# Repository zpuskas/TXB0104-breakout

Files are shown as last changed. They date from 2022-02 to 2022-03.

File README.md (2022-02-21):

# TXB0104 Breadboard Breakout

Breakout board for the TXB0104 bidirectional voltage-level translator IC with
automatic direction sensing. The main difference of this board compared to
[SparkFun's Voltage-Level Translator Breakout](https://www.sparkfun.com/products/11771)
is that the OE pin is independent, and not soldered to VCCA by default,
allowing for any side of the communication to be in control of the data flow
out of the box.

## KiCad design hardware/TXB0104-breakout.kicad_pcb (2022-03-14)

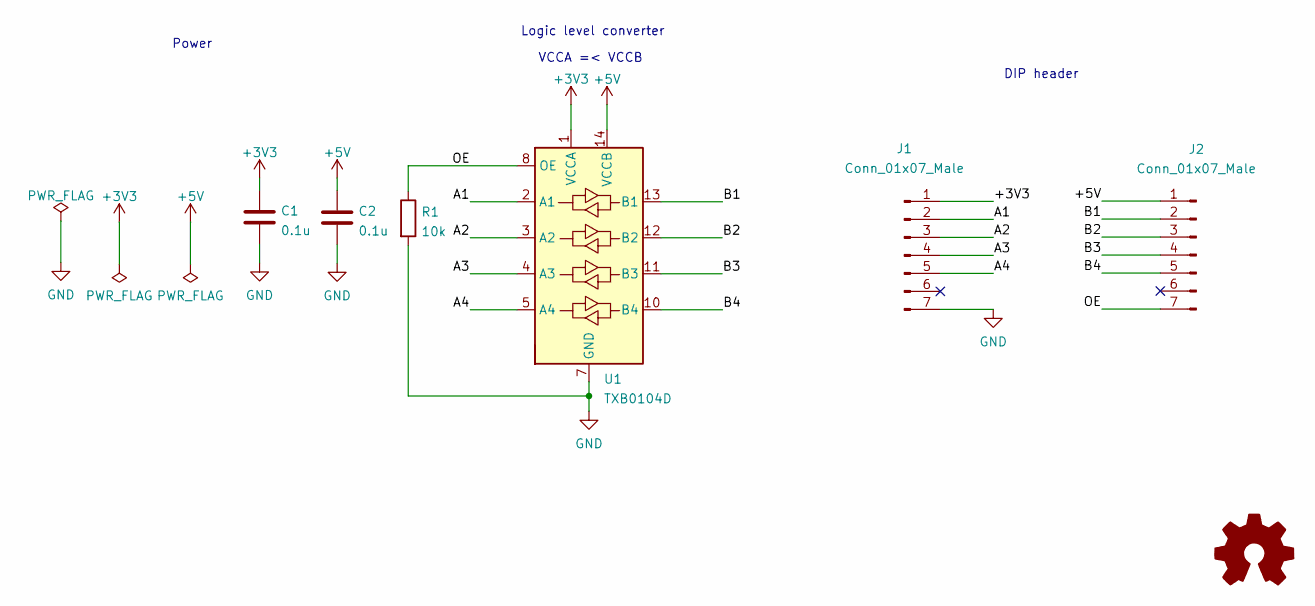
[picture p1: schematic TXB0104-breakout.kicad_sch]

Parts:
C1, C2: 0.1u; C_0805_2012Metric_Pad1.18x1.45mm_HandSolder
J1, J2: Conn_01x07_Male; PinHeader_1x07_P2.54mm_Vertical
R1: 10k; R_0805_2012Metric_Pad1.20x1.40mm_HandSolder
U1: TXB0104D; SOIC-14_3.9x8.7mm_P1.27mm

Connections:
+3V3: C1.1, J1.1, U1.1 (VCCA)
+5V: C2.1, J2.1, U1.14 (VCCB)
/A1: J1.2, U1.2 (A1)
/A2: J1.3, U1.3 (A2)
/A3: J1.4, U1.4 (A3)
/A4: J1.5, U1.5 (A4)
/B1: J2.2, U1.13 (B1)
/B2: J2.3, U1.12 (B2)
/B3: J2.4, U1.11 (B3)
/B4: J2.5, U1.10 (B4)
/OE: J2.7, R1.1, U1.8 (OE)
GND: C1.2, C2.2, J1.7, R1.2, U1.7 (GND)

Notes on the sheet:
VCCA =< VCCB
Power
DIP header
Logic level converter

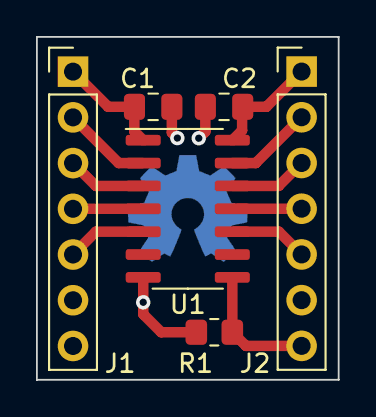
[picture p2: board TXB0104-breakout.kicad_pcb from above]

Board: 2 copper layers, 16.8 x 19.1 mm, 7 parts (1 on the bottom side), 12 nets.

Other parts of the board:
REF1: OSHW-Symbol_6.7x6mm_Copper

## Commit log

2022-02-20 Add first version of the breakout board
    This breakout board uses a TXB0104 level converter chip, that can be
    used to match communication buses between circuits operating at
    different voltages.
    [TXB0104-breakout.kicad_pcb, TXB0104-breakout.kicad_sch]
2022-03-06 Update board
    - add pull down resistor to output enable pin to ensure off state during
    power on
    - remove extra gound planes from the signal layer to reduce potential RF
    emissions from the board
    - fix bottom silk screen
    [TXB0104-breakout.kicad_pcb, TXB0104-breakout.kicad_sch]
2022-03-14 Fine tune PCB
    - Move ground vias for the bypass capacitors closer to power lines to
    reduce loop size
    - Update bottom silk screen text arrangement for more symmetry
    [TXB0104-breakout.kicad_pcb]
